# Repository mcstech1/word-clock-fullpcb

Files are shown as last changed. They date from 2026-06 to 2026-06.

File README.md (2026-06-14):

# Word Clock — Full-PCB build

After a decade of work on workclocks based on other open-source work, I've spent the last year or so on optimizing this design towards manufacturability. I've decided to publish this to contribute my little part. It might not be the cheapest, but AFAIK this is the easiest to assemble as it comes with a full PCB that can be ordered at any PCBA-Shop, here I refer to JLCPCB. The housing can be 3D printed with a BambuLab H2S or a similar-sized 3D printer (in parts and assembled using Acetone) or, if you have access to one, CNC-milled from PE or other material. When those parts are done, it's a simple drop in with a couple of screws and a bit of glue to include magnets, diffusor foil, LDR and power.

This is a **full-PCB** design — all **114 RGB LEDs (SK6812)** are mounted directly on a single board, driven by an
ESP8266 (ESP-12E), powered from a 5 V supply. No LED strips, no perfboard.

It runs the open-source [QlockWork](https://github.com/ch570512/Qlockwork) firmware (ESP8266).

| | |
|---|---|
| **Grid** | 11 × 10 letters + 4 corner dots = **114 LEDs** |
| **LEDs** | SK6812 PLCC4 5.0 mm (addressable RGB) |
| **Controller** | ESP8266 / ESP-12E |
| **Power** | 5 V / 6 A, DC barrel input |
| **Board** | single PCB carrying the full matrix |
| **Housing** | two options: 3D-printed *or* CNC-machined |
| **Firmware** | [QlockWork](https://github.com/ch570512/Qlockwork) |

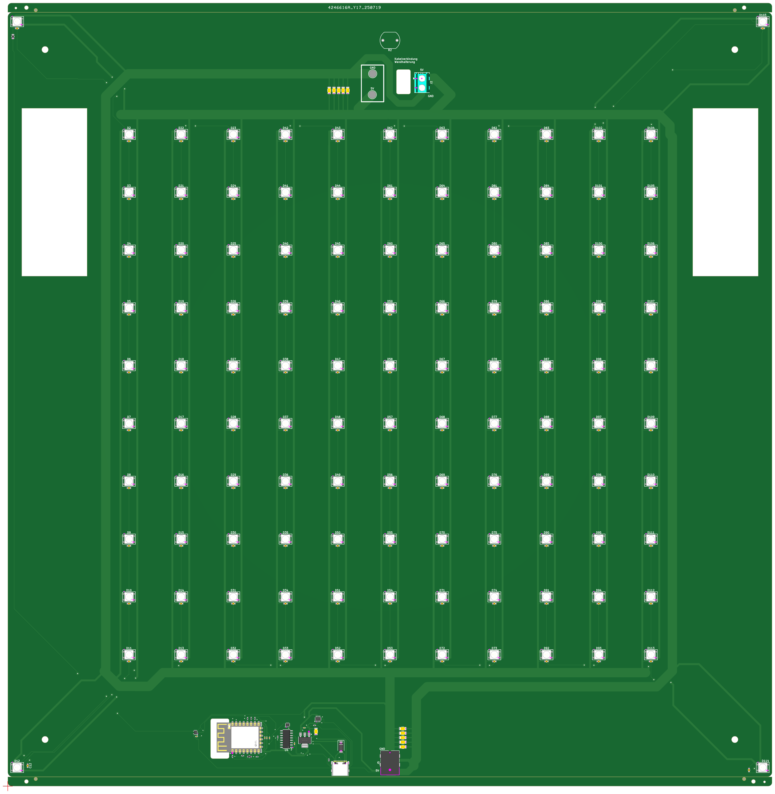
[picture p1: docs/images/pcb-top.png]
Fully-populated PCB — the whole LED matrix on a single board


> _The full-PCB board._

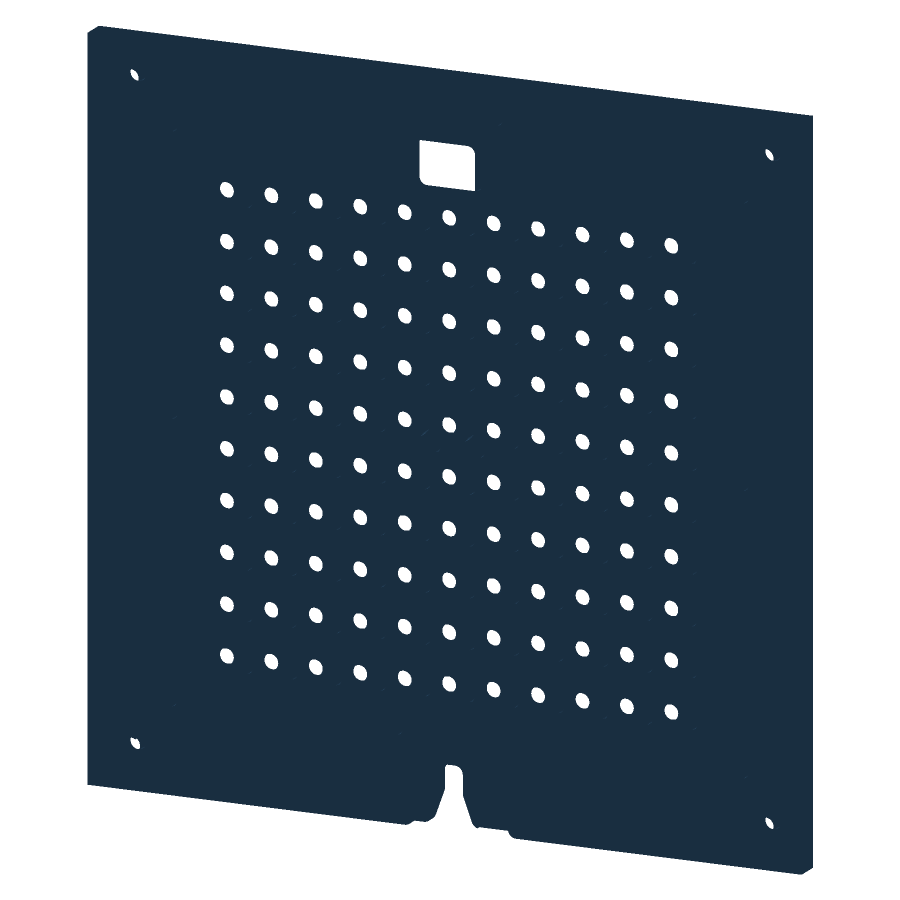
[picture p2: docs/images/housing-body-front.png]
Housing body (450 × 450 mm), rendered from the STEP file


> _Housing body (450 × 450 mm), rendered from the STEP file._

---

## What's in this repository

```
pcb/
  gerbers/         Gerber + drill files
  assembly/        BOM + CPL (JLCPCB SMT assembly)
housing/
  housing-body.step   main body — mill from solid (CNC) or convert/print
  base-plate.3mf      base plate — 3D-print, slicer-ready
  back-plate.3mf      back plate — 3D-print, slicer-ready
BOM.md             full build cost (PCB + parts + housing)
README.md          this file
LICENSE            CERN-OHL-S v2   ·   LICENSE-docs   CC-BY-SA 4.0
```

## How to build it

1. **Order the PCB (assembled).** Upload `pcb/gerbers/gerbers-upload.zip` to a fab (e.g. JLCPCB),
   then add `pcb/assembly/BOM_jlcpcb.xlsx` + `CPL_jlcpcb.xlsx` for SMT assembly of the LEDs /
   caps / diodes. See [BOM.md](BOM.md) for costs (~€72/board all-in at qty 5).
2. **Make the housing** — pick one route:
   - **3D-printed:** slice `housing/base-plate.3mf` + `housing/back-plate.3mf`. Depending on the printer, the housing cannot be printed in one piece. I've seperated these components into "puzzle parts" based on the print bed of a BambuLab H2S. The parts can then be fused using Acetone.
   - **CNC-machined:** mill `housing/housing-body.step` from a solid block of PE.
   - 9× Ø10×5 mm neodymium magnets hold the front/back together.
3. **Flash QlockWork** to the ESP8266 — see [Firmware & pinout](#firmware--pinout). A working
   `Configuration.h` for this board is included. NOTE: The clock needs to have external power while flashing to not overload the USB-port.

This is the exact board revision that was fabricated and **verified to work**. One issue is
known on this revision:

- **Power-supply polarity is reversed.** Connect the 5 V supply with **inverted polarity**
  (swap **+** / **−**).

## Firmware & pinout

The clock runs **[QlockWork](https://github.com/ch570512/Qlockwork)** on the ESP8266. The
included **`Configuration.h`** is a working config for this board — drop it into your QlockWork
build. Key hardware settings it uses:

| Setting | Value |
|---|---|
| LED data line | **GPIO15 / D8** (`PIN_LEDS_DATA`) |
| LDR (auto-brightness) | **A0** (`PIN_LDR`) |
| On-board status LED | GPIO2 / D4 |
| LED type | SK6812, **`NEOPIXEL_RGB`**, `NEO_GRB + NEO_KHZ800` |
| Pixel count | `NUMPIXELS 115` (114 LEDs + 1 unused index — harmless) |
| Matrix layout | `LED_LAYOUT_VERTICAL_1` (matches the vertical LED columns) |
| Front cover | `FRONTCOVER_DE_DE` (German — change to your language) |
| Disabled | buttons, IR receiver, buzzer, DHT22, RTC backup |

## Licence

**Copyright © 2026 mcstech1.**

- **Hardware & mechanical files** (Gerbers, BOM/CPL, STEP, 3MF): **CERN-OHL-S v2** —
  see [`LICENSE`](LICENSE).
- **Documentation, text & images:** **CC-BY-SA 4.0** — see [`LICENSE-docs`](LICENSE-docs).
- **Firmware** (QlockWork) is not included. The bundled **`Configuration.h`** stems from
  [QlockWork](https://github.com/ch570512/Qlockwork) and is licensed under **GNU GPL v3** (that
  project's licence), **not** the licences above.

If you build one, a link back is appreciated. Enjoy! ⏰

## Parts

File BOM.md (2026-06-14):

# Bill of materials & build cost

Two "BOMs" live in this project

1. **`pcb/assembly/BOM_jlcpcb.xlsx` + `CPL_jlcpcb.xlsx`** — the files you
   upload to **JLCPCB** for PCB assembly. Leave them as-is.
2. **This page** — the cost of the *complete* clock for someone rebuilding it.

Prices are real sourced parts (~mid-2026, incl. VAT — they fluctuate). PCB/assembly prices are
from the last JLCPCB order.

## Full build cost

Most parts are bought in **packs** (a 10-pack of LDRs, a box of screws, a 1 kg spool…) but one
clock only uses a fraction. The **share** column = the share of the pack one clock consumes, and
**€/clock = share × pack price**.

| # | Item | Buy as (pack) | Pack price | Used /clock | **share** | **€/clock** |
|---|---|---|---:|---:|---:|---:|
| 1 | **PCB + SMT assembly** (JLCPCB merchandise) | 5 boards | €298.13 | 1 board | 1/5 = 20 % | **€59.63** |
| 2 | **Shipping**| per order (5 boards) | €60.12 | — | 1/5 = 20 % | **€12.02** |
| 3 | **5 V / 6 A power adapter, EU** — [AliExpress](https://de.aliexpress.com/item/4000443793258.html) | 1 pc | €5.39 | 1 | 100 % | **€5.39** |
| 4 | **DC barrel jack / pigtail** 5.5×2.5 mm 90°, 30 cm — [AliExpress](https://de.aliexpress.com/item/1005009842534963.html) | 5-pc pack | €5.29 | 1 | 1/5 = 20 % | **€1.06** |
| 5 | **Neodymium magnets** N35 10×5 mm — [AliExpress](https://de.aliexpress.com/item/1005010158024883.html) | 60-pc pack | €9.59 | 10 | 10/60 = 17 % | **€1.60** |
| 6 | **Diffuser film** — [AliExpress](https://de.aliexpress.com/item/1005007519292019.html) | roll 40 × 300 cm | €5.59 | ~40 × 45 cm | ~15 % | **~€0.84** |
| 7 | **LDR** GL5528 (5 mm) — [eBay](https://www.ebay.de/itm/122233227066) | 10-pack | €3.49 | 1 | 1/10 = 10 % | **€0.35** |
| 8 | **Screws** M2.5 × 10 mm | box ~200 | ~€10.00 | 12 | 12/200 = 6 % | **~€0.60** |
| 9 | **ABS filament** — main body | 1 kg spool | ~€20.00 | 317 m ≈ 0.80 kg | 80 % | **~€16.00** |
| 10 | **PLA filament** — back plate | 1 kg spool | ~€20.00 | 140 m ≈ 0.42 kg | 42 % | **~€8.40** |
| — | _CNC alternative to #9 + #10_ | block PE | €__ | 1 | — | €__ |
| | | | | | **Total:** | **≈ €106** |

(Per-clock subtotal of the small parts #3–8: PSU €5.39 + jack €1.06 + magnets €1.44 + film €0.84 + LDR €0.35 + screws €0.60 ≈ **€9.7**. The wall mount is printed as part of the housing.)

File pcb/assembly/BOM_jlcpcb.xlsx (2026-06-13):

Comment | Designator | Footprint | JLCPCB Part #（optional）
 | D12,D99,D101,D19,D86,D11,D104,D22,D111,D62,D80,D23,D90,D76,D97,D39,D25,D4,D112,D82,D92,D73,D24,D106,D33,D16,D49,D2,D87,D42,D60,D32,D17,D79,D14,D63,D85,D89,D66,D54,D38,D107,D52,D75,D30,D37,D13,D98,D103,D102,D71,D27,D50,D61,D81,D64,D100,D58,D53,D77,D29,D55,D88,D56,D96,D43,D45,D59,D40,D26,D94,D47,D1,D7,D70,D78,D20,D83,D21,D46,D105,D110,D109,D31,D93,D41,D6,D34,D113,D5,D9,D44,D15,D74,D67,D108,D10,D95,D72,D69,D68,D57,D36,D51,D114,D65,D35,D28,D84,D8,D3,D18,D48,D91 | LED_SK6812_PLCC4_5.0x5.0mm_P3.2mm | C5378720
 | C12,C91,C98,C11,C65,C105,C103,C24,C53,C4,C90,C55,C108,C2,C76,C93,C82,C45,C23,C50,C75,C68,C72,C102,C37,C104,C83,C92,C10,C71,C46,C78,C5,C88,C111,C42,C112,C28,C47,C6,C48,C31,C7,C101,C34,C32,C3,C89,C27,C60,C21,C49,C44,C26,C106,C84,C57,C58,C64,C59,C110,C85,C20,C87,C66,C25,C81,C96,C107,C63,C38,C15,C97,C41,C43,C9,C67,C80,C74,C17,C29,C14,C70,C35,C62,C13,C40,C52,C99,C30,C100,C8,C79,C56,C39,C51,C19,C36,C22,C114,C33,C86,C69,C1,C73,C94,C77,C113,C16,C109,C95,C61,C18,C54 | C_0603_1608Metric | C14663
 | R12 | R_0402_1005Metric | C25117
 | R6,R7,R3,R4,R11 | R_0402_1005Metric | C25744
 | C118,C119,C120,C127,C123,C125,C124,C128,C126,C122,C121 | C_1206_3216Metric | C15008
 | J5 | PWRM-TN_XDJK-060B-055 | C18202141
 | C129,C131 | C_0402_1005Metric | C1525
 | J3 | USB-C_SMD-TYPE-C-31-M-12 | C2927038
 | R9 | R_0402_1005Metric | C25741
 | J2 | TerminalBlock_MaiXu_MX126-5.0-02P_1x02_P5.00mm | C3703
 | U6 | SOT-23-6 | C5180249
 | C117,C115 | C_0402_1005Metric | C1525
 | U4 | SOIC-16_3.9x9.9mm_P1.27mm | C7464026
 | R8 | R_0603_1608Metric | C22961
 | C116,C130 | C_0402_1005Metric | C15525
 | Q1 | SC-70-6_L2.2-W1.3-P0.65-LS2.1-BR | C62892
 | U2 | SOT-353_SC-70-5 | C151417
 | R16,R15 | R_0402_1005Metric | C25905
 | U3 | SOT-223 | C6186
 | R1 | R_0805_2012Metric | C2828837
 | D115 | D_SMA | C2480
 | U5 | ESP-12E | C82891

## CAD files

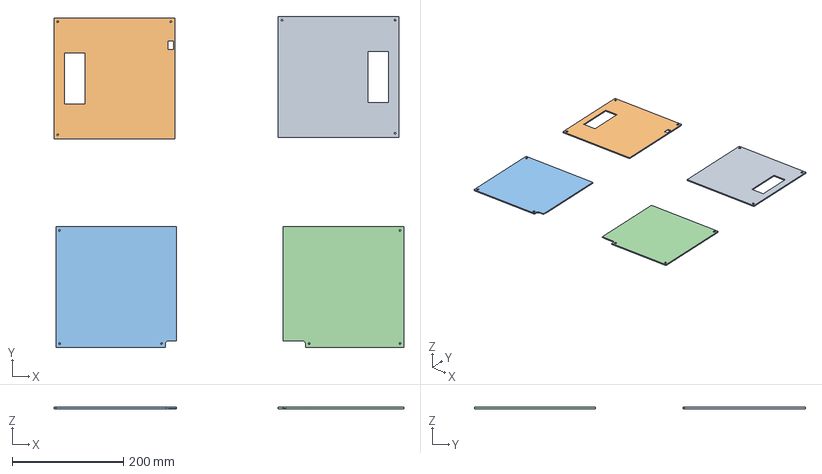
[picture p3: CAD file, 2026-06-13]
housing/back-plate.3mf
628.2 x 594.3 x 3.00 mm

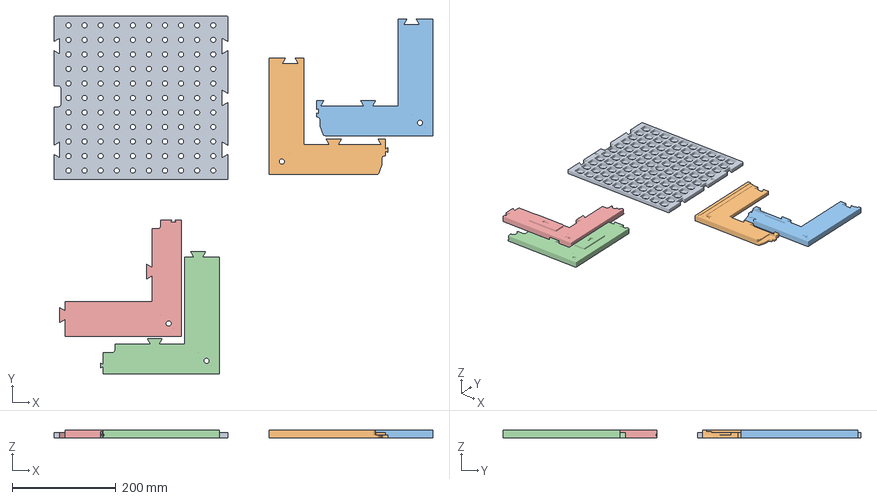
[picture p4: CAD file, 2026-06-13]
housing/base-plate.3mf
730.6 x 689.2 x 15.5 mm

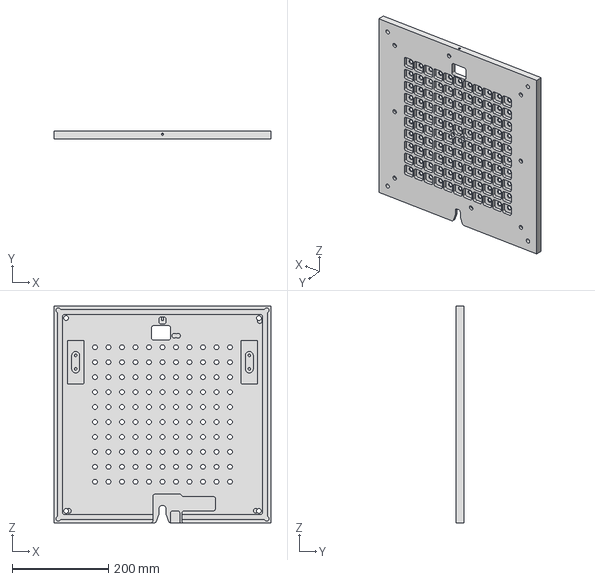
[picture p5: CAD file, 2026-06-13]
housing/housing-body.step
450.0 x 16.0 x 450.0 mm

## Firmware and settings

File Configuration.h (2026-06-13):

//*****************************************************************************
// Configuration.h
//
// This file stems from the QlockWork firmware (https://github.com/ch570512/Qlockwork)
// and is licensed under the GNU GPL v3 — the same licence as QlockWork. It is the working configuration for
// this board (114× SK6812, LED data on GPIO15/D8, LDR on A0, vertical layout).
// See the project README "Firmware & pinout" section for details.
//
// See README.txt for help
//*****************************************************************************

#ifndef CONFIGURATION_H
#define CONFIGURATION_H

//*****************************************************************************
// Software settings
//*****************************************************************************

#define HOSTNAME "QLOCKWORK"
#define WEBSITE_TITLE "QLOCKWORKs page"
//#define DEDICATION "The only reason for time is so that everything doesn't happen at once.<br>(Albert Einstein)"
#define WIFI_SETUP_TIMEOUT 120
#define WIFI_AP_PASS "12345678"
#define OTA_PASS "1234"
#define NTP_SERVER "pool.ntp.org"
#define SHOW_IP
//#define WIFI_BEEPS

//#define NONE_TECHNICAL_ZERO
#define AUTO_MODECHANGE_TIME 60 // seconds
#define EVENT_TIME 300 // seconds
#define ALARM_LED_COLOR RED
//#define ABUSE_CORNER_LED_FOR_ALARM

//#define POWERON_SELFTEST
#define SHOW_MODE_AMPM
#define SHOW_MODE_SECONDS
#define SHOW_MODE_WEEKDAY
#define SHOW_MODE_DATE
#define SHOW_MODE_MOONPHASE
//#define SHOW_MODE_SUNRISE_SUNSET // works only if APIKEY is defined
#define SHOW_MODE_TEST

//#define APIKEY "xxxxxxxxxxxxxxxxxxxxxxxxxxxxxxxx"
#define LOCATION "Berlin, DE"
//#define LOCATION "Zurich, CH"
//#define LOCATION "Hong Kong, HK"

//#define FRONTCOVER_EN
#define FRONTCOVER_DE_DE
//#define FRONTCOVER_DE_SW
//#define FRONTCOVER_DE_BA
//#define FRONTCOVER_DE_SA
//#define FRONTCOVER_DE_MKF_DE
//#define FRONTCOVER_DE_MKF_SW
//#define FRONTCOVER_DE_MKF_BA
//#define FRONTCOVER_DE_MKF_SA
//#define FRONTCOVER_D3
//#define FRONTCOVER_CH
//#define FRONTCOVER_CH_GS
//#define FRONTCOVER_ES
//#define FRONTCOVER_FR
//#define FRONTCOVER_IT
//#define FRONTCOVER_NL
//#define FRONTCOVER_BINARY

//*****************************************************************************
// Timezone
//*****************************************************************************

//#define TIMEZONE_IDLW  // IDLW  International Date Line West UTC-12
//#define TIMEZONE_SST   // SST   Samoa Standard Time UTC-11
//#define TIMEZONE_HST   // HST   Hawaiian Standard Time UTC-10
//#define TIMEZONE_AKST  // AKST  Alaska Standard Time UTC-9
//#define TIMEZONE_USPST // USPST Pacific Standard Time (USA) UTC-8
//#define TIMEZONE_USMST // USMST Mountain Standard Time (USA) UTC-7
//#define TIMEZONE_USAZ  // USAZ  Mountain Standard Time (USA) UTC-7 (no DST)
//#define TIMEZONE_USCST // USCST Central Standard Time (USA) UTC-6
//#define TIMEZONE_USEST // USEST Eastern Standard Time (USA) UTC-5
//#define TIMEZONE_AST   // AST   Atlantic Standard Time UTC-4
//#define TIMEZONE_BST   // BST   Eastern Brazil Standard Time UTC-3
//#define TIMEZONE_VTZ   // VTZ   Greenland Eastern Standard Time UTC-2
//#define TIMEZONE_AZOT  // AZOT  Azores Time UTC-1
//#define TIMEZONE_GMT   // GMT   Greenwich Mean Time UTC
#define TIMEZONE_CET     // CET   Central Europe Time UTC+1
//#define TIMEZONE_EST   // EST   Eastern Europe Time UTC+2
//#define TIMEZONE_MSK   // MSK   Moscow Time UTC+3 (no DST)
//#define TIMEZONE_GST   // GST   Gulf Standard Time UTC+4
//#define TIMEZONE_PKT   // PKT   Pakistan Time UTC+5
//#define TIMEZONE_BDT   // BDT   Bangladesh Time UTC+6
//#define TIMEZONE_JT    // JT    Java Time UTC+7
//#define TIMEZONE_CNST  // CNST  China Standard Time UTC+8
//#define TIMEZONE_HKT   // HKT   Hong Kong Time UTC+8
//#define TIMEZONE_PYT   // PYT   Pyongyang Time (North Korea) UTC+8.5
//#define TIMEZONE_CWT   // CWT   Central West Time (Australia) UTC+8.75
//#define TIMEZONE_JST   // JST   Japan Standard Time UTC+9
//#define TIMEZONE_ACST  // ACST  Australian Central Standard Time UTC+9.5
//#define TIMEZONE_AEST  // AEST  Australian Eastern Standard Time UTC+10
//#define TIMEZONE_LHST  // LHST  Lord Howe Standard Time UTC+10.5
//#define TIMEZONE_SBT   // SBT   Solomon Islands Time UTC+11
//#define TIMEZONE_NZST  // NZST  New Zealand Standard Time UTC+12

//*****************************************************************************
// Hardware settings
//*****************************************************************************

#define SERIAL_SPEED 115200

#define NUMPIXELS 115

//#define ONOFF_BUTTON
//#define MODE_BUTTON
//#define TIME_BUTTON

#define ESP_LED

#define MIN_BRIGHTNESS 20
#define MAX_BRIGHTNESS 255
#define TEST_BRIGHTNESS 80

//#define SENSOR_DHT22
#define DHT_TEMPERATURE_OFFSET 0.5
#define DHT_HUMIDITY_OFFSET -2.0

//#define RTC_BACKUP
#define RTC_TEMPERATURE_OFFSET -1.15

#define LDR
//#define LDR_IS_INVERSE
#define LDR_HYSTERESIS 80
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

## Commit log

2026-06-13 Open-source full-PCB word clock: PCB, housing, BOM, firmware config, docs
    [BOM_jlcpcb.xlsx, Configuration.h, back-plate.3mf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]
2026-06-14 Updated BOM, wrong No of magnets
